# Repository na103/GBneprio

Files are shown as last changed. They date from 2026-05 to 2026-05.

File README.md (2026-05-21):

## GameBoy  compatible 2MB Flash Cart 
A classic Game Boy Cart with only a 2MB flash ROM, designed for low cost and low power consumption.</BR>
Derived from the MBC5/MBC1 hybrid by insideGadgets and adapted to the ATF1502 logic CPLD.
</BR></BR>
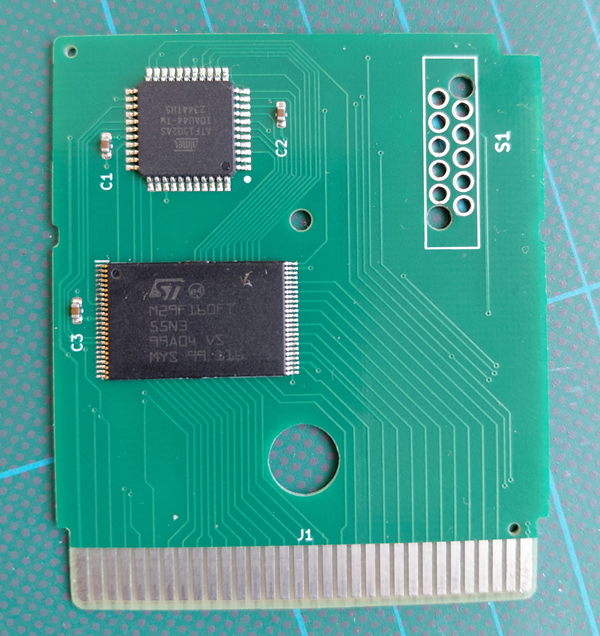
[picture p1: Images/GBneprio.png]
GBneprio


## Bill of materials
| Qt. | Description | Designator | JLCPCB part | Mouser part |
|:---:|---|---|---|---|
|3 |Capacitor 100nF |C1,C2,C3 |C106221 | CC0603ZRY5V9BB104 |
|1 |CPLD |U1 |C1521098 | ATF1502AS-10AU44 |
|2 |16Mbit Flash Rom |U2 |C1015902 | M29F160FT55N3E2 |

## Note

Please note that the PCB thickness must be 0.8mm.</br>
In the PCB Assembly folder, you can find the BOM and CPL files for production and assembly with JLCPCB.</br>
To program the CPLD, you will need a compatible JTAG programmer (e.g., Atmel ATDH1150USB) and the SKEDD connector from Wurth Elektronik (code 490107671012).</br>
When programming the CPLD from the JTAG connector, you must supply the board with 5V separately.</br>

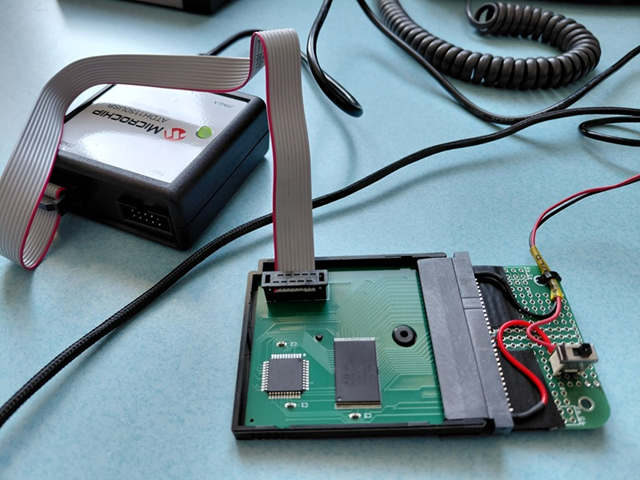
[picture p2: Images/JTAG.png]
JTAG


If you found this my work useful, please consider buying me a cup of coffee if you want:<br>


## License

This work is licensed under a Creative Commons Attribution 4.0 International License. See [https://creativecommons.org/licenses/by/4.0/](https://creativecommons.org/licenses/by/4.0/).

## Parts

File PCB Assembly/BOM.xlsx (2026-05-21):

Comment | Designator | Footprint | JLCPCB Part #（optional）
ATF1502AS-10AU44 | U1 | TQFP-44(10x10) | C1521098
M29F160FT55N3E2 | U2 | TSOP-48-12.0mm | C1015902
100nF | C1 | 0603 | C106221
100nF | C2 | 0603 | C106221
100nF | C3 | 0603 | C106221

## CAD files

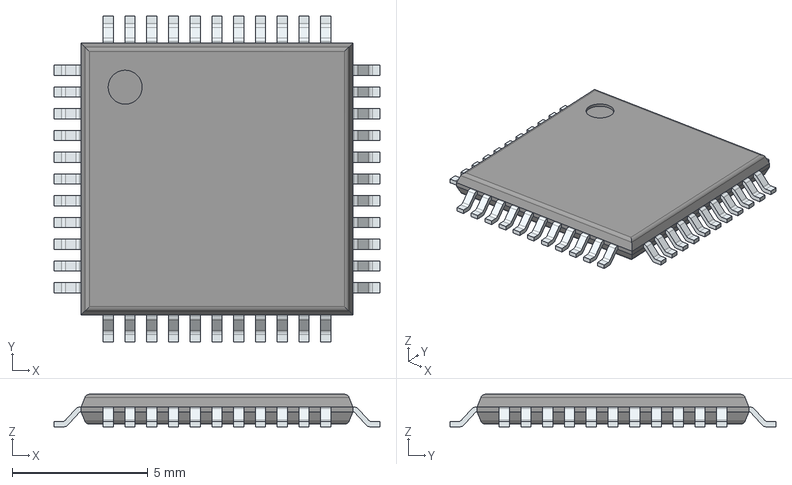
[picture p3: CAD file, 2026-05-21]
Kicad/ATF1502AS-10AU44/3D/ATF1502AS-10AU44.stp
12.0 x 12.0 x 1.20 mm
PinsArrayLR
PinsArrayTB

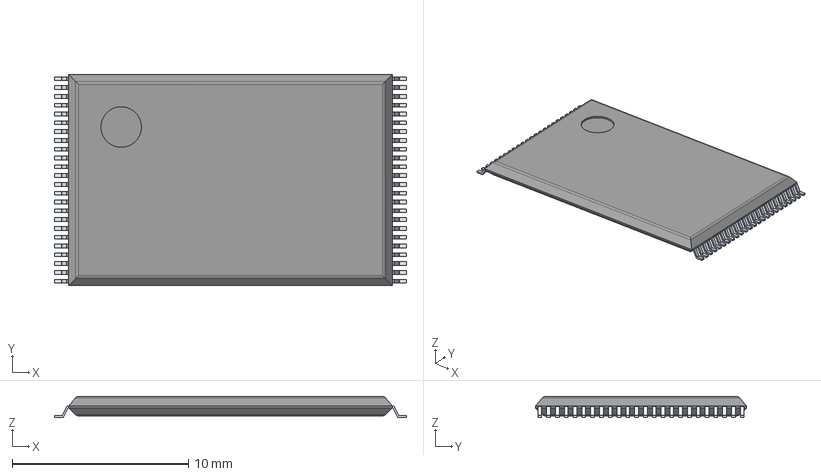
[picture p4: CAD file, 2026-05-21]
Kicad/M29F160FT/3D/M29F160FT55N3E2.stp
20.0 x 12.0 x 1.20 mm
PinsArrayLR

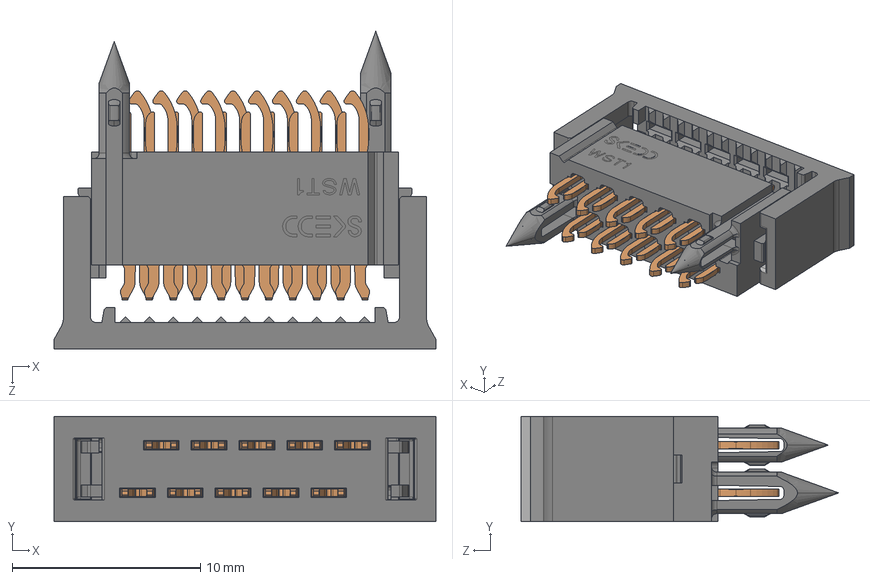
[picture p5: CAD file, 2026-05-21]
Kicad/490107671012/490107671012.stp
20.3 x 5.60 x 16.9 mm

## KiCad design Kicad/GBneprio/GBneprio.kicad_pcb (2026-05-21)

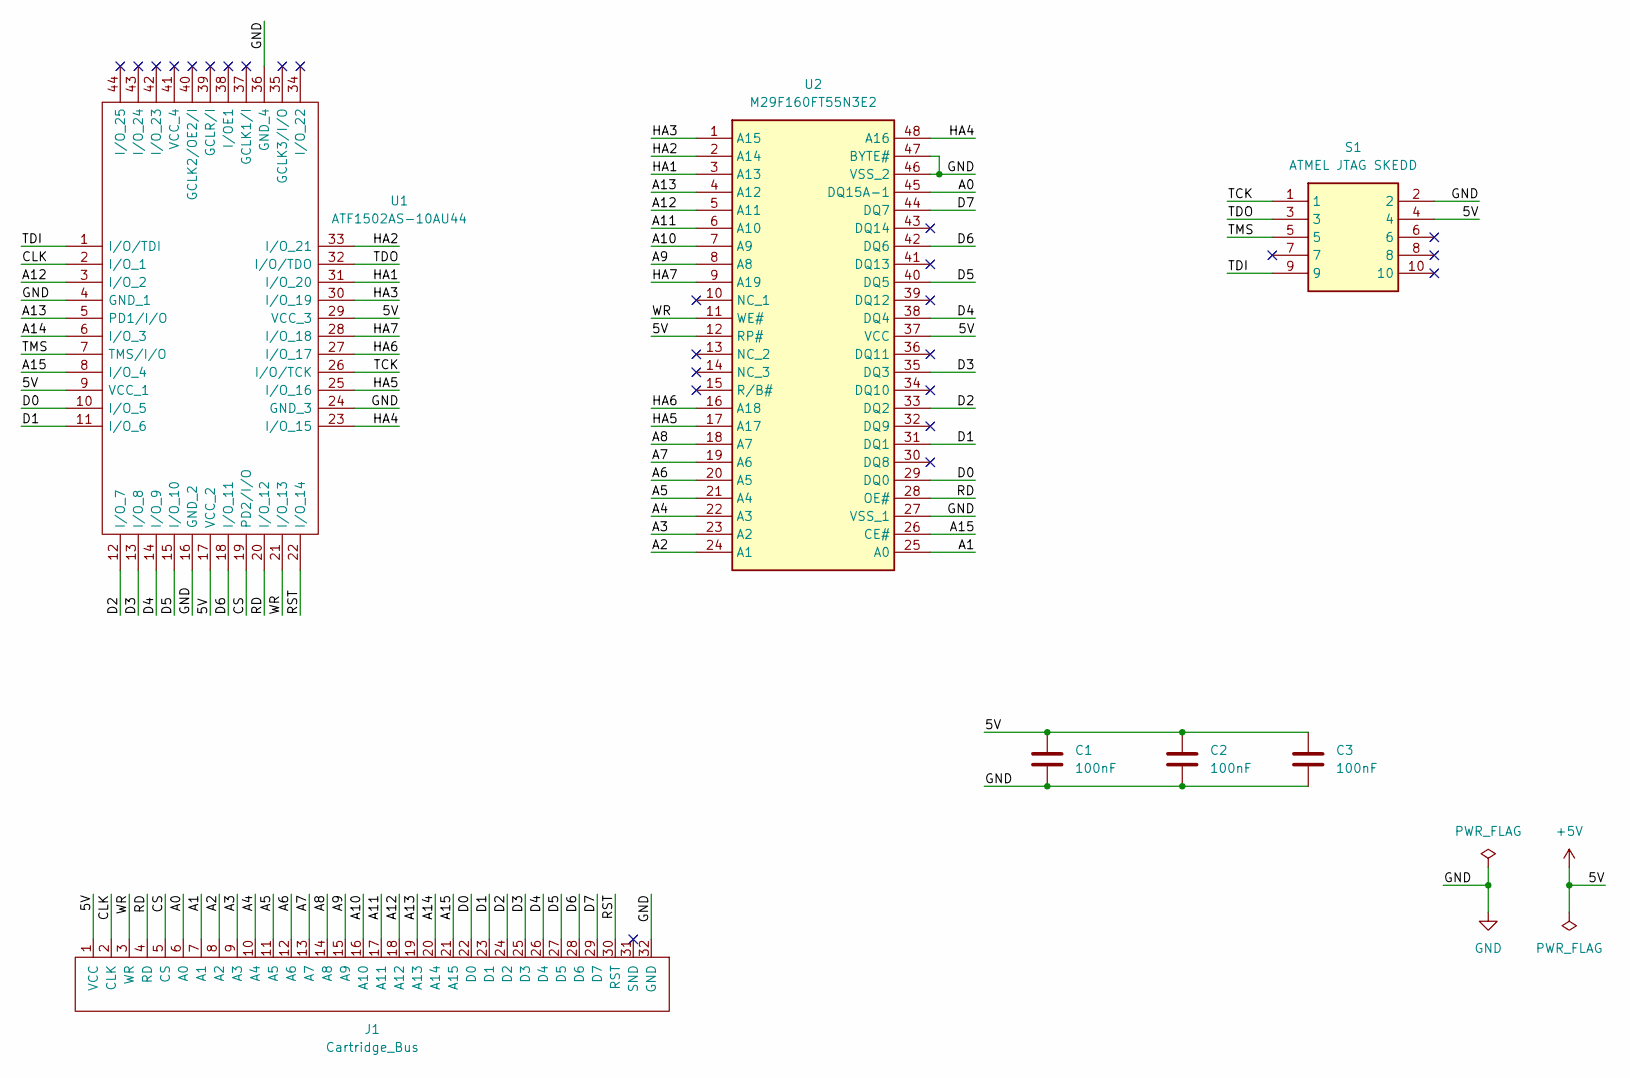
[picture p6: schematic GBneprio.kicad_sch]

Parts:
C1, C2, C3: 100nF; C_0603_1608Metric_Pad1.08x0.95mm_HandSolder
J1: Cartridge_Bus; GB_Cartridge
S1: ATMEL JTAG SKEDD; 490107671012; Mouser Part Number 710-490107671012
U1: ATF1502AS-10AU44; QFP80P1200X1200X120-44N; Mouser Part Number 556-AF1502AS10AU44
U2: M29F160FT55N3E2; SOP50P2000X120-48N; Mouser Part Number 913-M29F160FT55N3E2

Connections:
+5V: C1.1, C2.1, C3.1, J1.1 (VCC), S1.4, U1.9 (VCC_1), U1.17 (VCC_2), U1.29 (VCC_3), U2.12 (RP#), U2.37 (VCC)
/A0: J1.6 (A0), U2.45 (DQ15A-1)
/A1: J1.7 (A1), U2.25 (A0)
/A2: J1.8 (A2), U2.24 (A1)
/A3: J1.9 (A3), U2.23 (A2)
/A4: J1.10 (A4), U2.22 (A3)
/A5: J1.11 (A5), U2.21 (A4)
/A6: J1.12 (A6), U2.20 (A5)
/A7: J1.13 (A7), U2.19 (A6)
/A8: J1.14 (A8), U2.18 (A7)
/A9: J1.15 (A9), U2.8 (A8)
/A10: J1.16 (A10), U2.7 (A9)
/A11: J1.17 (A11), U2.6 (A10)
/A12: J1.18 (A12), U1.3 (I/O_2), U2.5 (A11)
/A13: J1.19 (A13), U1.5 (PD1/I/O), U2.4 (A12)
/A14: J1.20 (A14), U1.6 (I/O_3)
/A15: J1.21 (A15), U1.8 (I/O_4), U2.26 (CE#)
/CLK: J1.2 (CLK~), U1.2 (I/O_1)
/CS: J1.5 (CS), U1.19 (PD2/I/O)
/D0: J1.22 (D0), U1.10 (I/O_5), U2.29 (DQ0)
/D1: J1.23 (D1), U1.11 (I/O_6), U2.31 (DQ1)
/D2: J1.24 (D2), U1.12 (I/O_7), U2.33 (DQ2)
/D3: J1.25 (D3), U1.13 (I/O_8), U2.35 (DQ3)
/D4: J1.26 (D4), U1.14 (I/O_9), U2.38 (DQ4)
/D5: J1.27 (D5), U1.15 (I/O_10), U2.40 (DQ5)
/D6: J1.28 (D6), U1.18 (I/O_11), U2.42 (DQ6)
/D7: J1.29 (D7), U2.44 (DQ7)
/HA1: U1.31 (I/O_20), U2.3 (A13)
/HA2: U1.33 (I/O_21), U2.2 (A14)
/HA3: U1.30 (I/O_19), U2.1 (A15)
/HA4: U1.23 (I/O_15), U2.48 (A16)
/HA5: U1.25 (I/O_16), U2.17 (A17)
/HA6: U1.27 (I/O_17), U2.16 (A18)
/HA7: U1.28 (I/O_18), U2.9 (A19)
/RD: J1.4 (RD), U1.20 (I/O_12), U2.28 (OE#)
/RST: J1.30 (RST), U1.22 (I/O_14)
/TCK: S1.1, U1.26 (I/O/TCK)
/TDI: S1.9, U1.1 (I/O/TDI)
/TDO: S1.3, U1.32 (I/O/TDO)
/TMS: S1.5, U1.7 (TMS/I/O)
/WR: J1.3 (WR), U1.21 (I/O_13), U2.11 (WE#)
GND: C1.2, C2.2, C3.2, J1.32 (GND), S1.2, U1.4 (GND_1), U1.16 (GND_2), U1.24 (GND_3), U1.36 (GND_4), U2.27 (VSS_1), U2.46 (VSS_2), U2.47 (BYTE#)

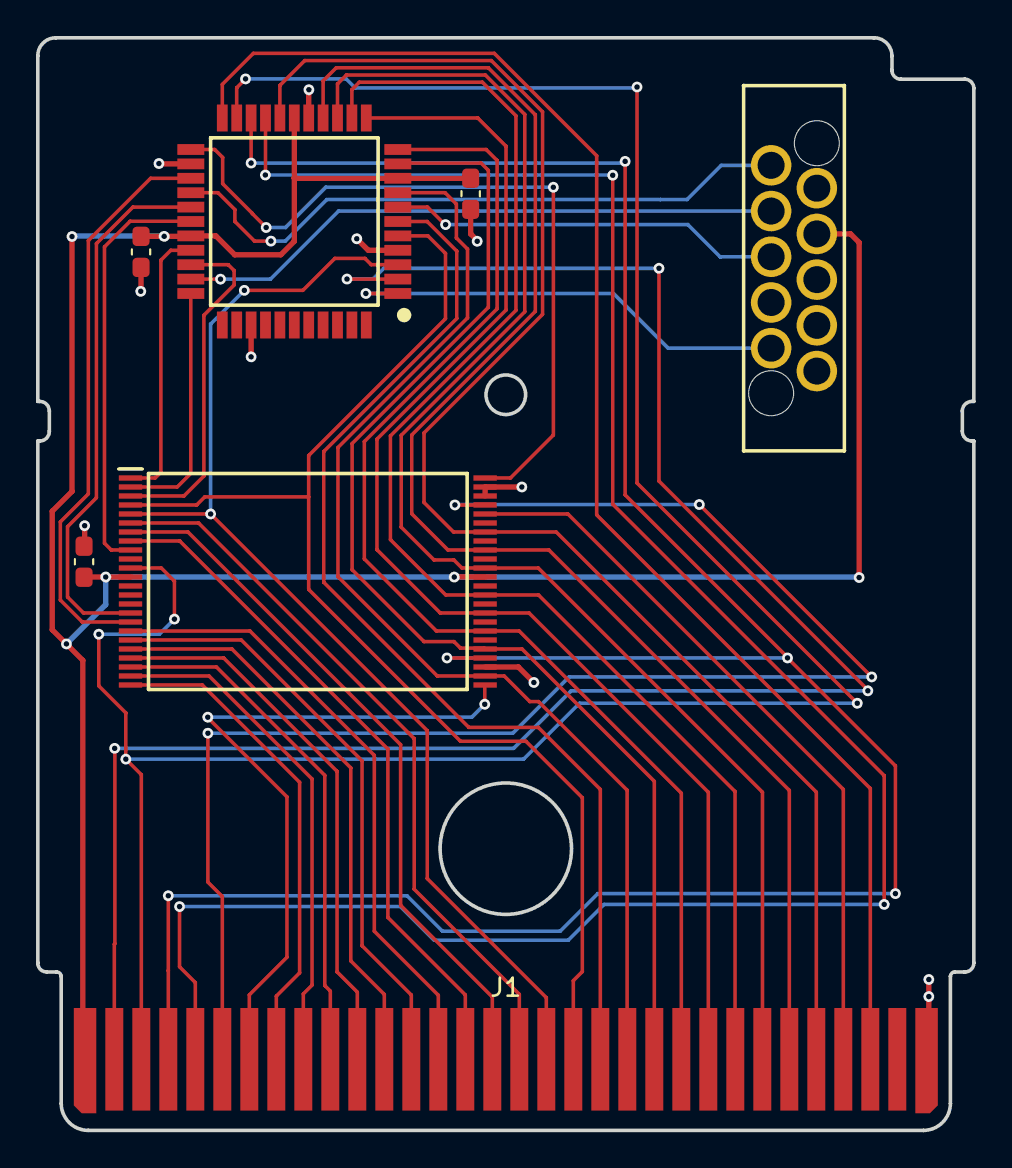
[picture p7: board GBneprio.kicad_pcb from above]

Board: 2 copper layers, 52.0 x 60.7 mm, 7 parts (0 on the bottom side), 42 nets.

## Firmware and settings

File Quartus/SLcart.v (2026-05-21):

/*
 Gameboy MBC5/MBC1 Hybrid - 2MB ROM

*/

module SLcart (
reset, 
clock,
inputAddress, inputData, inputCE, inputWR, inputRD,
highAddress);

input reset;
input clock;
input [3:0] inputAddress; 
input [6:0] inputData; 
input inputCE;
input inputRD;
input inputWR;

output [6:0] highAddress; 
reg [6:0] highAddress;

reg [6:0] romBank; 

reg mbc1Detect303FOn;
reg mbc1Detected607F;
reg mbc3or5Locked;


always @ (reset or clock or inputCE or inputRD or inputWR) begin
	if (!reset) begin
		highAddress <= 7'b0;
		romBank <= 7'b1;
		mbc1Detect303FOn <= 1'b0;
		mbc1Detected607F <= 1'b0;
		mbc3or5Locked <= 1'b0;
	end
	else begin

		if (inputAddress <= 4'd7 && (!inputRD || !inputWR)) begin
			if (inputAddress <= 4'd3) begin 
				highAddress <= 7'b0; 
			end
			else begin
				highAddress <= (romBank << 1); 
			end
		end
		

		if (((inputAddress == 4'd2) || inputAddress == 4'd3 && mbc1Detect303FOn) && !inputWR && inputRD && inputCE) begin
			if (inputData == 7'd0) begin
				romBank <= 1'b1;
				mbc1Detect303FOn <= 1'b1;
			end
			else begin
				if (inputData >= 7'd32) begin
					mbc3or5Locked <= 1'b1;
				end
				
				romBank <= inputData;
			end
		end
		

		if ((inputAddress == 4'd6 || inputAddress == 4'd7) && !inputWR && inputRD && inputCE) begin
			mbc1Detected607F <= 1'b1;
		end
	end
end


endmodule

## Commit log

2026-05-21 kicad project
    [490107671012.stp, ATF1502AS-10AU44.stp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]
2026-05-21 assembly file
    [BOM.xlsx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]
